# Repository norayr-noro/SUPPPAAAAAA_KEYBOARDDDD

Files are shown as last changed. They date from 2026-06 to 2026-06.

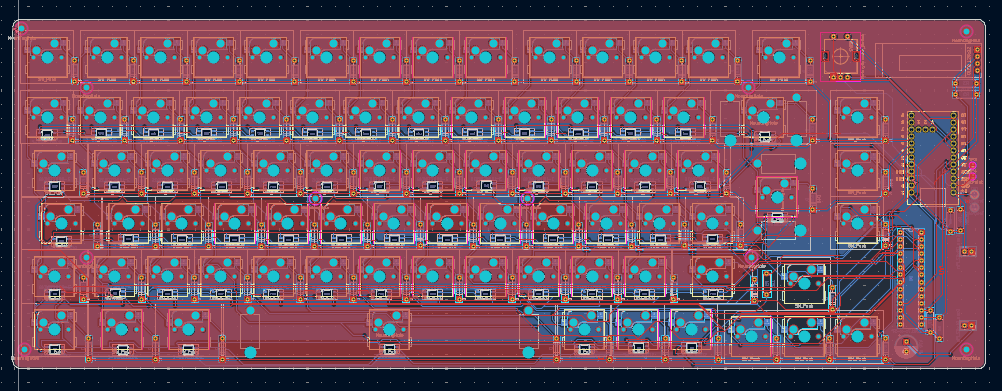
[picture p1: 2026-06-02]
SUPA_photos/PCB_full.png

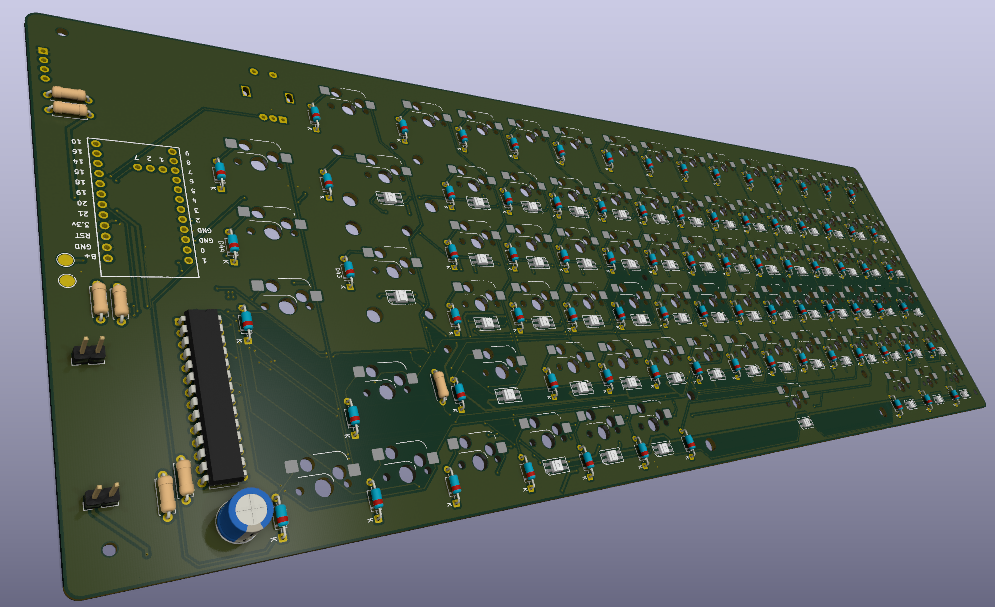
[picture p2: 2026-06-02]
SUPA_photos/PCB_3d(back).png

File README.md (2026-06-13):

# SUPPPAAAAAA_KEYBOARDDDD


This project is my version of a custom mechanical keyboard, brimmed up to the max with upgrades (which gives it the name suppaaaaaaa) for comparability to modern proffesional keyboards. It is inspired by the Keychron-V1-Max, but everything is custom, from the plate and case to the pcb and schematic! Before getting into this, I'd also like to say how much diffucult It sounded at first, but I think this is one of the best ways to learn how to design and layout a PCB, CAD and all sorts of stuff from this one project (thats one of the reasons why I wanted to this)!!!

# BOM
Here I'll put down all the components I will likely use in the full project (some of this is subject to change, esp. the switches):
| Item | URL | quantity needed | price total (USD) |
| ---- | ---- | --- | --- |
| cherry-mx style switches | https://tinyurl.com/46ueewwa | 82 | 33.74 | 
| Diodes (1N5817) | https://www.rapidonline.com/st-1n5817-schottky-diode-20v-1a-do41-47-2564 | 82 | 16.16 | 
| 330 ohm resistor  (THT) | https://tinyurl.com/3mh5jma3 | 1 | 2.29 | 
| 4.7K ohm resistor (THT) | https://tinyurl.com/2bpn6xam | 4 | 6.06 |
| 820K ohm resistor (THT) | https://tinyurl.com/4xysbk3m | 1 | 0.02 |
| 2 Mohm resistor (THT) |  https://tinyurl.com/4fxpa99j | 1 | 2.07 | 
| Nice!Nano v2 |  	https://shorturl.at/wlaR4 | 1 | 8.48 | 
| EC11 rotary encoder | https://www.ebay.co.uk/itm/113261494197?var=413549335980 | 1 | 4.94 |
| TPO4056 |  https://www.ebay.co.uk/itm/405070463792?chn=ps&_ul=GB&mkevt=1&mkcid=28&google_free_listing_action=view_item | 1 | 2.42 | 
| LiPo 10000mah 3.7v (battery) | https://tinyurl.com/yc5u3hex | 1 |8.36 | 
| OLED 0.91" | 	https://shorturl.at/Vc0Sg | 1 |5.25 | 
| SS11D10 slide switch | 	https://shorturl.at/1174X | 1 |2.06 |
| USB-A dongle (wireless) |  https://shorturl.at/GAQIp | 1  |  8.07 | 
| SK6812MINI-E (RGB-LED) |  https://tinyurl.com/37m9v9hy | 62 |  4.46 |
| 470 uf capacitor (THT) | https://www.rapidonline.com/panasonic-eca1vm471-470uf-20-35v-85-c-radial-aluminium-electrolytic-11-2172 | 1 |  0.44 |
| MT3608 DC to DC | 	https://tinyurl.com/52ezaaav | 1 |  1.59 |
| kalih hotswap sockets |  	https://tinyurl.com/452x8dtk | 82 |  4.94 |
| (Optional) | URL | quantity | price |
| ----------- | ---- | ------- | ---- | 
| O-rings | 	https://tinyurl.com/y44esxp9 | 82 | 5.38 |
| keycap foam pads | https://tinyurl.com/4kc52tvw | 82 | 9.94 |
| foam gaskets | 	https://tinyurl.com/5hd465du | 82 | 6.48 |
 
 Notes on the BOM: Firstly, I would like to say that the keys I chose are quite expensive, and if needed, can easily be replaced by much, much cheaper ones (if you want to, of course  I chose these because their peak and sound reallllly good). Secondly, you can change the lipo too to a bit bigger or smaller type, I chose 10000mAh since it was a nice middle number between huge and smaller similar lipos. Also, the DC-DC converter is there for the RGB LEDs to power them at 5V optimally instead of the half-working 3V3 it would get from the lipo or the MCU. And lastly, the optional section, like the O-rings, the hot-swap sockets, are there if you want to, but the PCB would work fine without them.

# 🧠 Design
This project started out by firstly making the schematic, loosely following the design by Scotto Keebs on [YouTube(https://www.youtube.com/joe_scotto)]

The microcontroller is used to control the entire PCB, kinda like the brain of the PCB. For this build, I'll be using the Nice!Nano v2, since It would have more GPIO pins than the Xiao seeduino using the same nrf52840 chip, and It has the same wifi and Bluetooth capabilities (also really good documentation for custom keyboard firmware). I also added a Gpio extender for the columns of the switches just because I ran out and chose to stick with the nice nano, and that there would be too many variable changes. (if you want you could change the mcu and extender design to a picoW or something with an nrf52840 chip, and it wouldn't really change a lot)

In my design, I'll be using a DC-DC converter step-up to efficiently power the SK6212 MINI-E RGB-LEDs, which run on 5V instead of the 3v3 which the rest of the board runs. And for the power I'll be using a cheap TP4056 for the usb-c power and a big 10000mah LiPo battery for the long time able to use.

I'll also be using a USB-A dongle for low-latency communication to the laptop/PC 
The extra addons I have added is a rotary encoder knob, likely which would be used in sound config, an OLED 0.91' screen for cool displays and battery charge, plus the hot-swap sockets and the rgb lighting for that premium look!!!! (and also the optional addons which are not in the total price but may also be added for that nice keyboard feeling yk)

(schematic and PCB)

PCB_full

For the PCB KiCad was used for the schematic and PCB layout and a plugin for the production files
And for the 3d models of the case and plate, Fusion360 was used just because it's one of the free versions of CAD software and imo one of the easier software to learn and use

# ⚙️ Firmware
-(n/a)

# 💭 Final Thoughts
This project was definitely harder than you'd expect it would be, but it was one of the coolest projects I think I have done, and I hope to finish this early to actualy see the full thing assembled

Photos of the finished CAD model and the PCB !!!!
Plate_(final)
PCB_full(diff perc )
CAD_FULL
bottomcase_final
topcase_(final)

(with the PCB
full_parts
full_parts2
)

(oh and also the assembled full model available in the 3d case + plate folder as *full_asembly.step* )
full_assembly2
full_assembly
(Also, don't flame me for making the assembly pcb look so low-detail. I tried to put the fully modeled PCB in, but my potato laptop kept crashing, so don't judge OK?)

PCB_3d(front)
(front and back of PCB)
PCB_3d(back)

I'll also attach the .step file for the PCB and the .f3d file for the 3d model i have worked on to this repository for future reference...

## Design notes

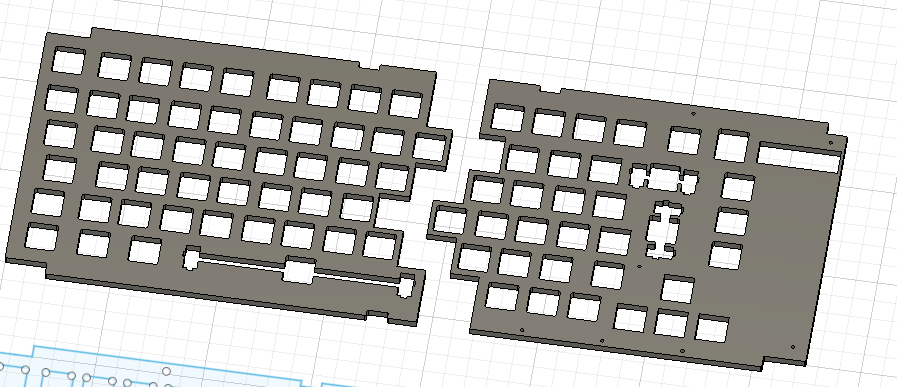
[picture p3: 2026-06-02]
SUPA_photos/Plate_(final).png

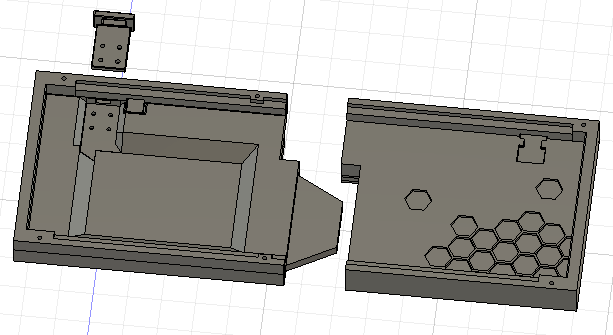
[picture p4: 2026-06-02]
SUPA_photos/bottomcase_final.png

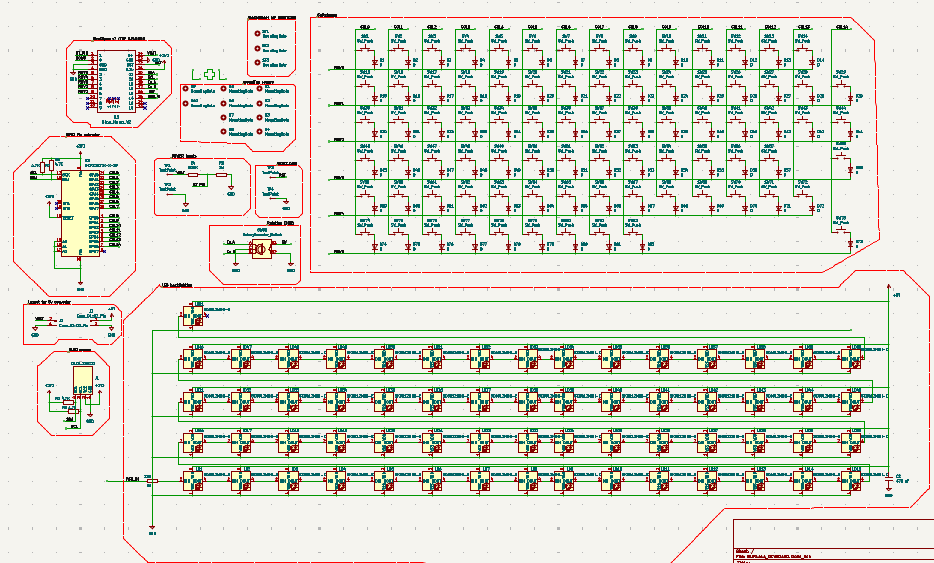
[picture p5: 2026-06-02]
SUPA_photos/Screenshot 2026-05-20 112616.png

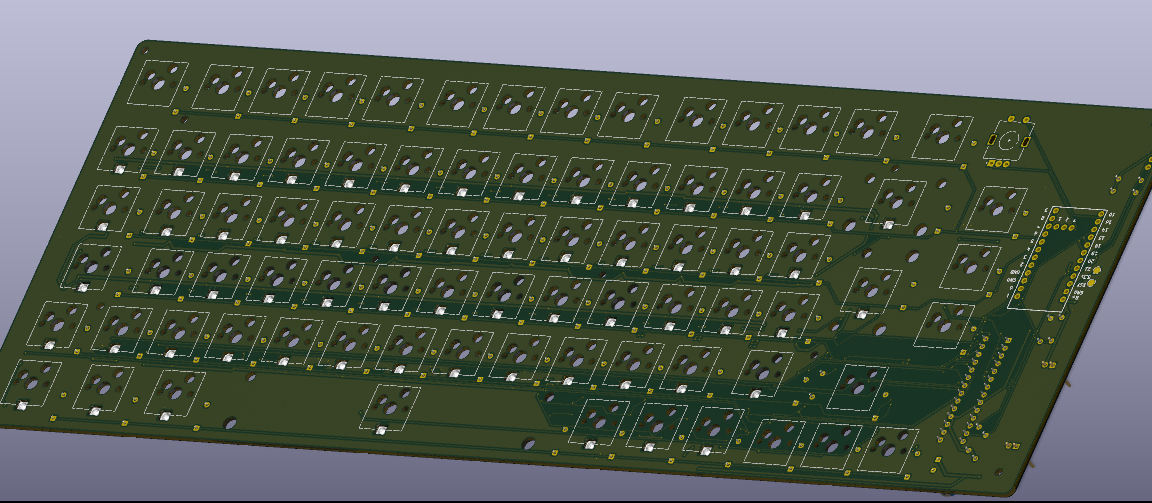
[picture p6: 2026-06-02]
SUPA_photos/PCB_3d(front).png

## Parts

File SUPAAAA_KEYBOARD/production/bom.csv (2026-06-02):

Designator | Footprint | Quantity | Value | LCSC Part #
C2 | CP_Radial_D8.0mm_P3.50mm | 1 | 470 uf
D1, D10, D11, D12, D13, D14, D15, D16, D17, D18, D19, D2, D20, D21, D22, D23, D24, D25, D26, D27, D28, D29, D3, D30, D31, D32, D33, D34, D35, D36, D37, D38, D39, D4, D40, D41, D42, D43, D44, D45, D46, D47, D48, D49, D5, D50, D51, D52, D53, D54, D55, D56, D57, D58, D59, D6, D60, D61, D62, D63, D64, D65, D66, D67, D68, D69, D7, D70, D71, D72, D73, D74, D75, D76, D77, D78, D79, D8, D80, D81, D82, D9 | D_DO-35_SOD27_P7.62mm_Horizontal | 82 | D
J1 | OLED_128x32 | 1 | OLED_128x32
J2, J3 | PinHeader_1x02_P2.54mm_Vertical | 2 | Conn_01x02_Pin
LD1, LD10, LD11, LD12, LD13, LD14, LD15, LD16, LD17, LD18, LD19, LD2, LD20, LD21, LD22, LD23, LD24, LD25, LD26, LD27, LD28, LD29, LD3, LD30, LD31, LD32, LD33, LD34, LD35, LD36, LD37, LD38, LD39, LD4, LD40, LD41, LD42, LD43, LD44, LD45, LD46, LD47, LD48, LD49, LD5, LD50, LD51, LD52, LD53, LD54, LD55, LD56, LD57, LD58, LD59, LD6, LD60, LD61, LD7, LD8, LD9 | LED_SK6812MINI-E_3.2x2.8mm_P1.5mm_ReverseMount | 61 | SK6812MINI-E
R1 | R_Axial_DIN0207_L6.3mm_D2.5mm_P7.62mm_Horizontal | 1 | 330
R2, R3, R6, R7 | R_Axial_DIN0207_L6.3mm_D2.5mm_P7.62mm_Horizontal | 4 | 4.7K
R4 | R_Axial_DIN0207_L6.3mm_D2.5mm_P7.62mm_Horizontal | 1 | 820K
R5 | R_Axial_DIN0207_L6.3mm_D2.5mm_P7.62mm_Horizontal | 1 | 2M
SW1, SW10, SW11, SW12, SW13, SW14, SW15, SW16, SW17, SW18, SW19, SW2, SW20, SW21, SW22, SW23, SW24, SW25, SW26, SW27, SW29, SW3, SW31, SW32, SW33, SW34, SW35, SW36, SW37, SW38, SW39, SW4, SW40, SW41, SW42, SW44, SW46, SW47, SW48, SW49, SW5, SW50, SW51, SW52, SW53, SW54, SW55, SW56, SW57, SW58, SW6, SW60, SW61, SW62, SW63, SW64, SW65, SW66, SW67, SW68, SW69, SW7, SW70, SW72, SW73, SW78, SW79, SW8, SW80, SW81, SW82, SW9 | Hotswap_MX_1.00u | 72 | SW_Push
SW28 | Hotswap_MX_2.00u | 1 | SW_Push
SW30, SW59, SW74, SW75, SW76 | Hotswap_MX_1.25u | 5 | SW_Push
SW43 | Hotswap_MX_ISOEnter | 1 | SW_Push
SW45, SW71 | Hotswap_MX_1.50u | 2 | SW_Push
SW77 | Hotswap_MX_6.25u | 1 | SW_Push
SW85 | RotaryEncoder_Alps_EC11E-Switch_Vertical_H20mm | 1 | RotaryEncoder_Switch
TP1, TP2 | TestPoint_Pad_D2.5mm | 2 | TestPoint
TP3, TP4 | TestPoint_Pad_D2.0mm | 2 | TestPoint
U2 | Nice_Nano_V2 | 1 | Nice_Nano_V2
U3 | DIP-28_W7.62mm | 1 | MCP23017x-x-SP

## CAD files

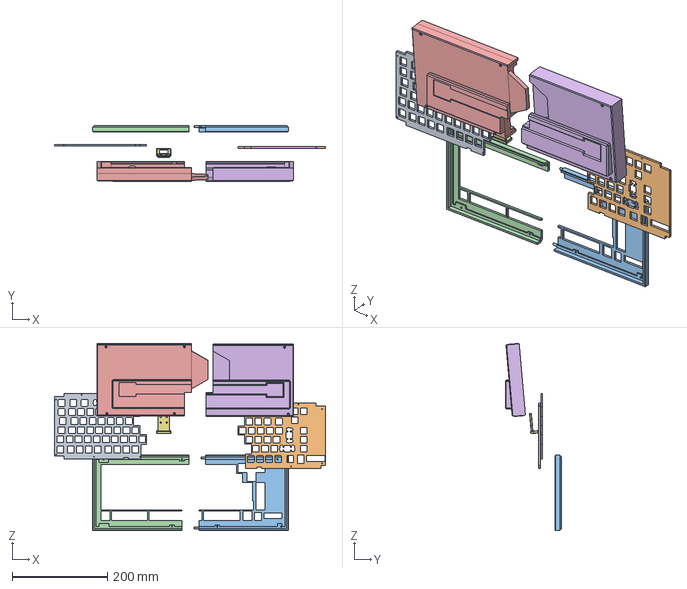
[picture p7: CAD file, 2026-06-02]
3D Case + plate/full_case+plate.step
569.3 x 118.6 x 393.4 mm

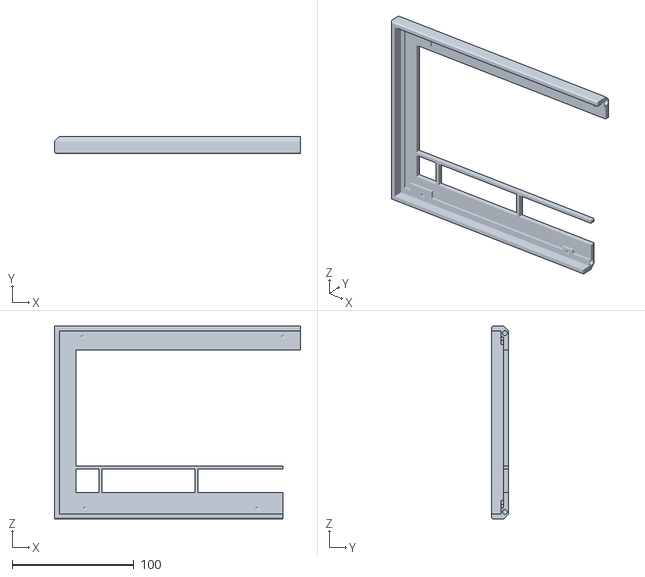
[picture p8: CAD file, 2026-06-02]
3D Case + plate/top_case_1.stl
202.2 x 14.0 x 158.4

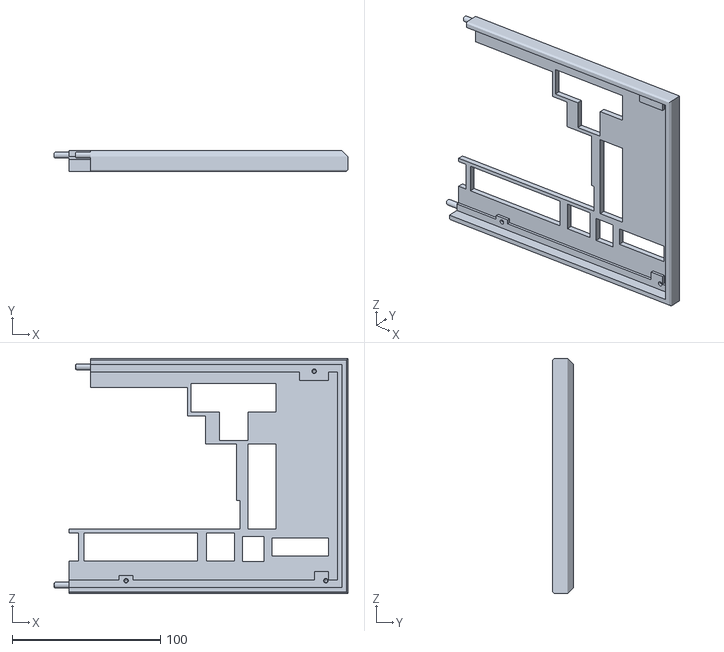
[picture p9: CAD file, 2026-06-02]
3D Case + plate/top_case_2.stl
198.1 x 14.0 x 158.4

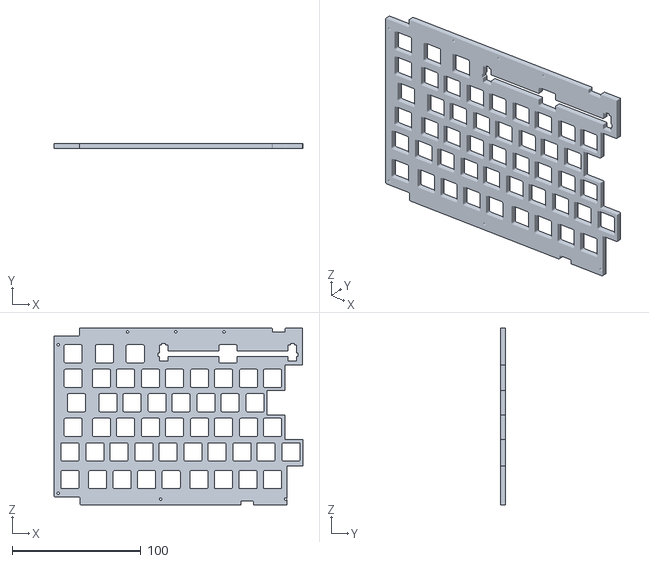
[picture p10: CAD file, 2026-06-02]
3D Case + plate/plate_1.stl
193.5 x 4.00 x 137.5

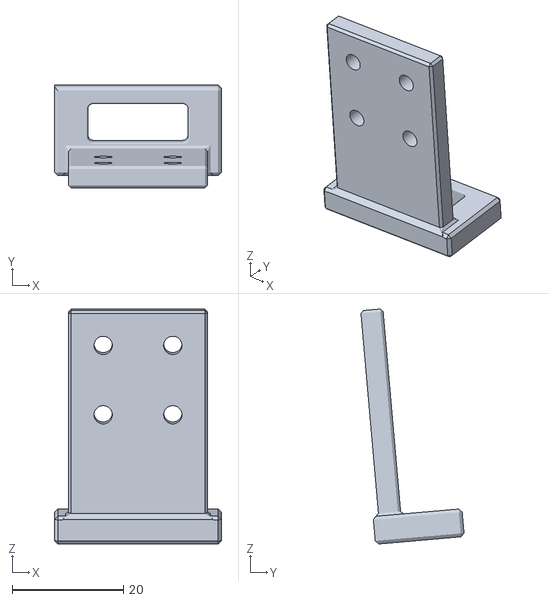
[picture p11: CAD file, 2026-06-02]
3D Case + plate/usb-c_addon.stl
30.0 x 18.5 x 42.2

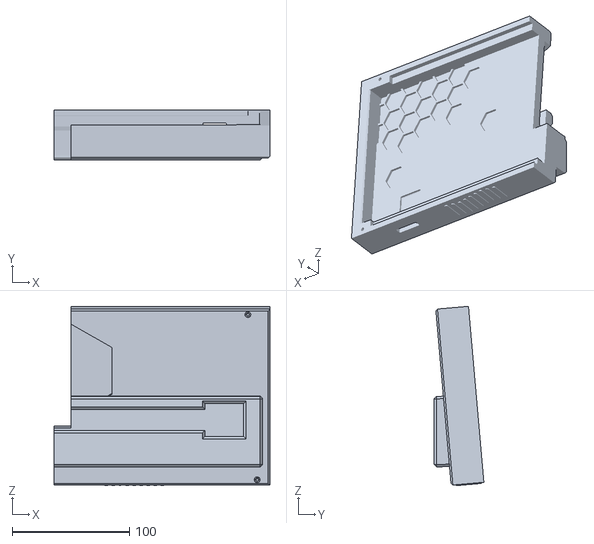
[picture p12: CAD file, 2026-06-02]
3D Case + plate/bottom_case_2.stl
183.9 x 42.4 x 152.7

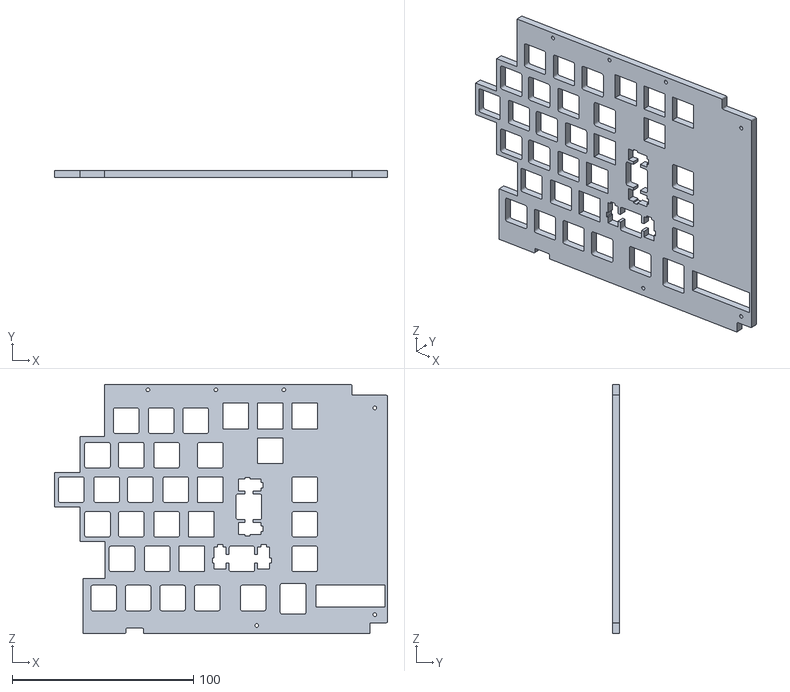
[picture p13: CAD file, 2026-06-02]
3D Case + plate/plate_2.stl
183.7 x 4.00 x 137.5

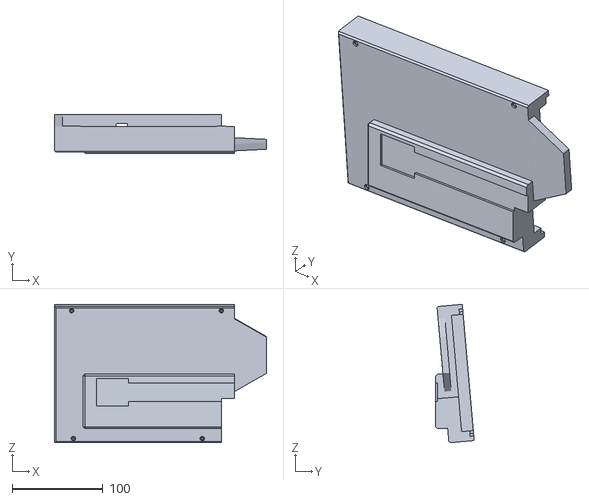
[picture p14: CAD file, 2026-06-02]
3D Case + plate/bottom_case_1.stl
233.2 x 42.4 x 152.1

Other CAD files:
3D Case + plate/full_case+plate.stl

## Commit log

2026-06-03 Revise README with project details and images
    Expanded project details, including BOM, design process, firmware, and final thoughts.
2026-06-13 Add files via upload
    + Here's the photos of the assembly
2026-06-13 Fix typos and enhance readability in README.md
    Corrected typos and improved clarity in the README. (oh and il also rewrote a most of the subheadings + forgot to update the firware part gonna do that now)
2026-06-13 Add keymap configuration for my_keyboard
    This file defines the keymap for the my_keyboard, including three layers: BASE, FN, and BT. Each layer specifies key bindings and sensor bindings for functionality.
2026-06-13 Add my_keyboard overlay configuration
    This overlay file defines the configuration for the my_keyboard, including I2C bus setup, GPIO expander, key matrix, rotary encoder, LED strip, and battery ADC. (im gonna go crazy before this works)
2026-06-13 Create build.yaml for firmware compilation
    Add build configuration for nice_nano_v2 board and my_keyboard shield.
2026-06-14 Add new remotes and projects to west.yml
    reason for change was that i think the reason for this not working was the fact that I think the error comes from the board not being properly specified since zmk dosent have exactly the nicenano v2 so i would get the name directly from nice keyboard git
2026-06-14 Update board name from nice_nano_v2 to nice_nano
    this might be the reason why7 it didnt work idk atp
2026-06-14 Update west.yml to remove projects and change revision
    Removed references to nicekeyboards and nicenano projects, updated zmk revision to v4.1.0. (might increase stabily of it working idk bro 😢 :)
2026-06-14 Update board name from nice_nano to nice_nano_v2
    turns out I was wrong shouldve just kept the same thing anywayssssssssssssss
2026-06-14 Refactor keyboard overlay configuration
    Updated GPIO expander and I2C bus configuration. Added battery sensing ADC and improved comments. (also I think the reason for the error this time was the outdated language used for the rotary encoders "don't quote me on that")
2026-06-15 Fix encoder reference in my_keyboard.overlay
    OK I used copilot for this just because I didnt understand the error correctly
2026-06-15 Fix encoder syntax in my_keyboard.overlay
2026-06-15 Refactor keyboard overlay configuration
    Removed the matrix transform definition and updated GPIO configurations for key scanning and rotary encoder.
2026-06-15 Fix sensor-bindings syntax for volume control
2026-06-15 Fix sensor-bindings syntax in my_keyboard.keymap
2026-06-15 Update sensor bindings for volume and brightness
2026-06-15 Update I2C pin configuration in my_keyboard overlay
2026-06-15 Refactor keyboard overlay for I2C and GPIO settings
    Updated the I2C bus configuration, added matrix transform for keymap, and modified GPIO settings for key scanning and LED control.
